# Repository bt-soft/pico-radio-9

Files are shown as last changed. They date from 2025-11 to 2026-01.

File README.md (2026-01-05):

# pico-radio-9

**A projekt még fejlesztés alatt áll!**

A projekt leírása: https://electrodiy.blog.hu/2026/01/01/pico_radio_fm_am_ssb_cw_rtty_sstv_wefax

## A kütyü
A kísérleti kütyü
<br/>

<em>A kísérleti kütyü (egy V7-es prototípus hangfrekis műveleti erősítővel kiegészítve)</em>
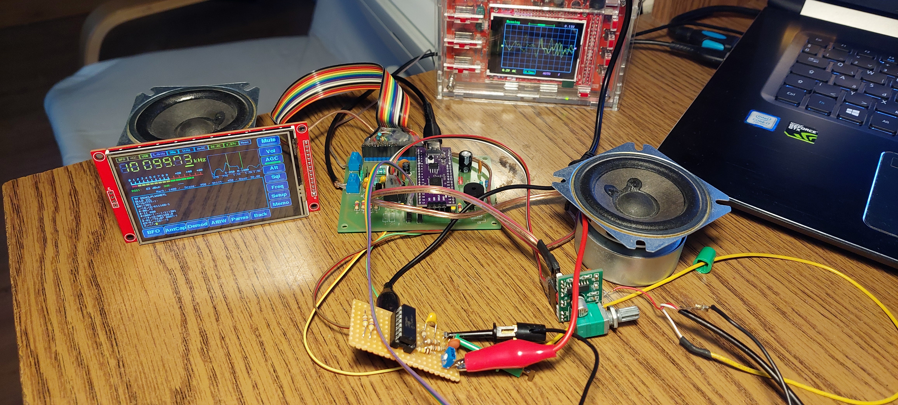
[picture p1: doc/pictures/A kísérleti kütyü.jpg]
A kísérleti kütyü

<br/>

### PCB 3D View

<table style="border:none; width:100%;">
  <tr>
    <td style="border:none; text-align:center; vertical-align:middle;">
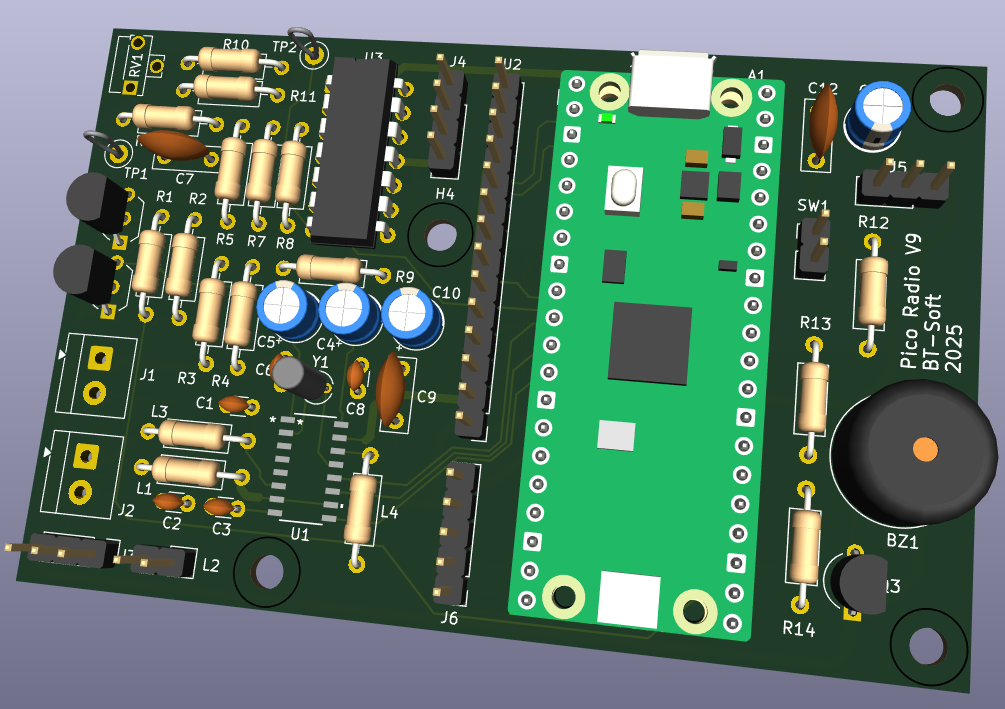
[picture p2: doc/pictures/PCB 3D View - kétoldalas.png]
PCB 3D View - kétoldalas
      
    </td>
    <td style="border:none; text-align:center; vertical-align:middle;">
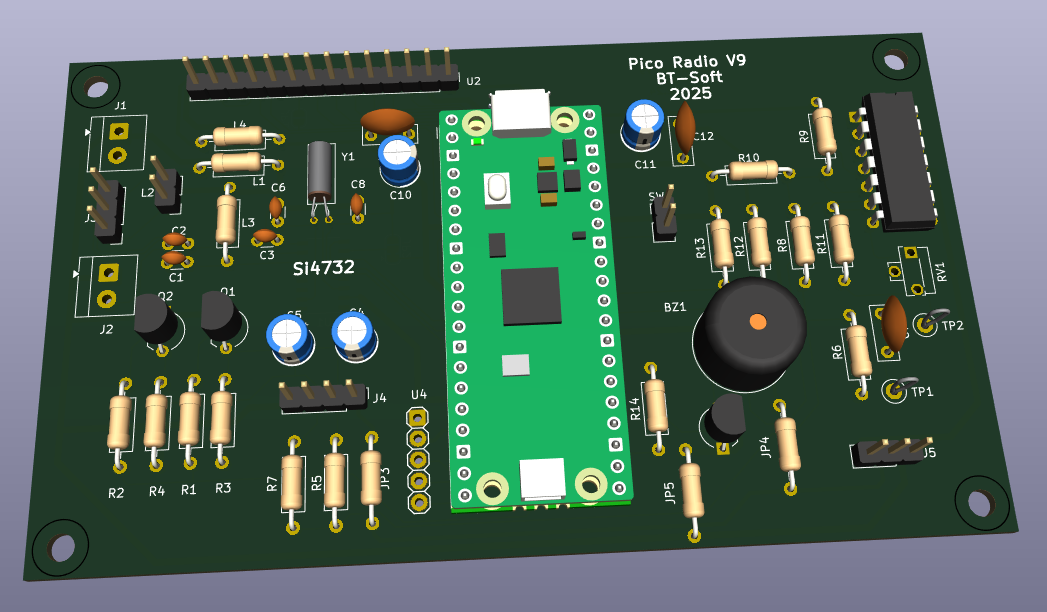
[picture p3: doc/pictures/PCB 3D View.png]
PCB 3D nézet - egyoldalas
      
    </td>
  </tr>
  <tr>
    <td style="border:none; text-align:center;">
      <em>Kétoldalas NYÁK terv</em>
    </td>
    <td style="border:none; text-align:center;">
      <em>Egyoldalas NYÁK terv</em>
    </td>
  </tr>
</table>

Egy Raspberry Pi Pico alapú rádióprojekt (Si4735 vezérléssel) — fejlett dekóderekkel (RTTY, CW, SSTV, WeFax), spektrum megjelenítéssel és interaktív érintőképernyős felülettel.

**Fő funkciók**
- Si4735 vezérlés (AM/FM/SDR jellegű demodok és RDS)
- Dekóderek: RTTY, CW, SSTV, WeFax, RTTY feldolgozó
- Valós idejű spektrum- és vízesés (low/high resolution bar, oscilloscope, envelope, waterfall, valamint CW/RTTY hangolássegéd waterfall és SNR burkoló) megjelenítők
- Hangfeldolgozó pipeline (AGC, FFT alapú vizualizáció manuális vagy automatikus erősítéssel)
- Rétegzett dialógus rendszer: többgombos dialógusok, értékmódosítók (rotary/touch)
- Konfigurációs tárolás EEPROM-ban (station/setting store)

## Architektúra
 - RP2040 / multicore: A Raspberry Pi Pico kétmagos RP2040 mikrovezérlője lehetővé teszi a feladatok elkülönítését (audio-feldolgozás a második magon, míg az első mag a UI/Si4735 vezérlést végzi). Ezt a projekt kihasználja a valós idejű audio dekódolás és UI műveletek párhuzamosítása érdekében.

## Technológiák

- Platform: Raspberry Pi Pico (RP2040)
- Fejlesztési környezet: PlatformIO 
- Framework: Arduino (RP2040 / Arduino core) 
- Nyelv: C++17 
- TFT vezérlés: `TFT_eSPI` — ILI9844 3.5" TFT grafikus megjelenítés és touch kezelése.
- Si4735 vezérlés: `PU2CLR SI4735` wrapper és a projekt saját `Si4735*` moduljai (I2C/SPI integráció és rádiófunkciók).
- Audio feldolgozás: FFT alapú spektrum- és vízesés (waterfall) megjelenítés, AGC és egyedi AudioProcessor pipeline.
- Dekóderek: RTTY, CW, SSTV, WeFax implementációk (saját `Decoder*` modulok).
- UI komponensek: egyedi komponenskeretrendszer (`UI*` osztályok) — dialógusok, többgombos menük, virtuális billentyűzet és grafikus komponensek.
- Időzítés és megszakítások: `RPI_PICO_TimerInterrupt` (PlatformIO lib) a pontos időzítéshez.
- FFT könyvtár: `arduinoFFT` a spektrum-számításokhoz.
- Helyi segédkönyvtárak: `lib/pico_sstv` az SSTV dekódoláshoz és segédfüggvényekhez.

## Felhasznált könyvtárak
- `Arduino-Pico`: https://github.com/earlephilhower/arduino-pico
- `TFT eSPI`: https://github.com/Bodmer/TFT_eSPI
- `RPI PICO TimerInterrupt`: https://github.com/khoih-prog/RPI_PICO_TimerInterrupt
- `PU2CLR SI4735`: https://github.com/pu2clr/SI4735
- `Arduino CMSIS-DSP`: https://www.arduinolibraries.info/libraries/arduino_cmsis-dsp
- `lib/pico_sstv`: https://github.com/dawsonjon/PicoSSTV

## Fájlok és modulok (összefoglaló)
- `src/` - forráskód (képernyők, dekóderek, UI komponensek, vezérlők)
  - `main.cpp`, `main-c1.cpp` - indító fájlok
  - `Screen*` - különböző képernyők (RTTY, CW, FM, AM, SSTV, WeFax, Setup, stb.)
  - `Decoder*` - dekóderek (RTTY, CW, SSTV, WeFax, stb.)
  - `UI*` - UI keretrensdszer komponensei (gombok, dialógusok, spektrum, textbox, stb.)
  - `Si4735*` - Si4735 kezelő és runtime logika
  - `AudioController.*`, `AudioProcessor-*` - audio pipeline és feldolgozás
- `include/` - header fájlok (összes osztály, UI, konfigurációs struktúrák)
  - `Config.h`, `ConfigData.h` - konfigurációs struktúrák és default értékek
  - `UIDialogBase.h`, `UIMultiButtonDialog.h`, `UIValueChangeDialog.h` - dialógusok és vezérlők
  - `UIHorizontalButtonBar.h` - alsó gombsor kezelése
- `lib/` - külső vagy saját könyvtárak (pl. `pico_sstv`, `CMSIS-DSP`)
- `doc/` - dokumentációs anyagok 
- `test/` - teszt erőforrások és példa adatállományok (pl. cw, rtty tesztek)

## Konfiguráció és mentés
- Konfigurációk a `Config` struktúrában találhatók (`include/Config.h`, `include/ConfigData.h`).
- Station / memory store beállítások EEPROM-ban tárolódnak (lásd `StationStore*` és `Eeprom*` fájlok).

## UI képernyők, dialógusok
- Rétegzett dialógus rendszer: a `UIScreen` tartalmaz egy dialógusstack-et, a `showDialog()` és `onDialogClosed()` mechanizmusokkal.
- Többgombos dialógusok: `UIMultiButtonDialog` + `UIValueChangeDialog` az értékek szerkesztéséhez.

## Szoftverarchitektúra
- Dekóderek: `src/Decoder*.cpp` — új dekóderek hozzáadása egyszerű az `IDecoder` interfész implementálásával.
- UI komponensek: `include/UI*`, `src/UI*` — gombok, dialógusok, új vizualizációk hozzáadása.
- Audio pipeline: `AudioController.cpp` és `AudioProcessor-*.cpp` fájlok tartalmazzák a feldolgozás logikáját.

## Hibakeresés / debug
- A forrásban `DEBUG(...)` makrók és logolási segédek találhatók. A debug build beállítása és a `__DEBUG` makró használata segíthet a problémakeresésben.

## Kapcsolási rajz / nyomtatott áramkör
- Kicad formátumban a `kicad` mappában (egy- és kétoldalas NYÁK tervvel).

---

## Harmadik féltől származó források
Az alábbi forrás nyújtottak inspirációkat a projekt fejlesztése és megvalósítása során.

 - **SI4735 + TFT példa (IU4ALH)**: https://github.com/IU4ALH/IU4ALH
  - Használat: Elsősorban a repó  `SI4735_2.8_TFT_SI5351_V.5.2b_Dark.zip` állományában található forrásokat használtam fel, amelyek inspirációt adtak a szolgáltatások, a képernyők felépítéséhez valamint az Si4735 beállítások kezeléséhez.

- **Rotary encoder / forgókapcsoló referencia**: https://www.mikrocontroller.net/articles/Drehgeber
  - Használat: A forgató encoder kezelésének elméleti háttere és debouncing/step logika inspirálására; segített a `RotaryEncoder` osztály és a forgóvezérlők finomhangolásában.

- **Pico SSTV implementáció**: https://github.com/dawsonjon/PicoSSTV
  - Használat: SSTV dekóder és mintafeldolgozó technikák inspirációjára használtam a projekt `DecoderSSTV` moduljának kialakításához.

- **fldigi**: https://github.com/w1hkj/fldigi
  - Használat: HF WeFax dekóder kiakalítása, technikai megoldások, szoftveres szűrők
---

## License
Projekt licenc: MIT

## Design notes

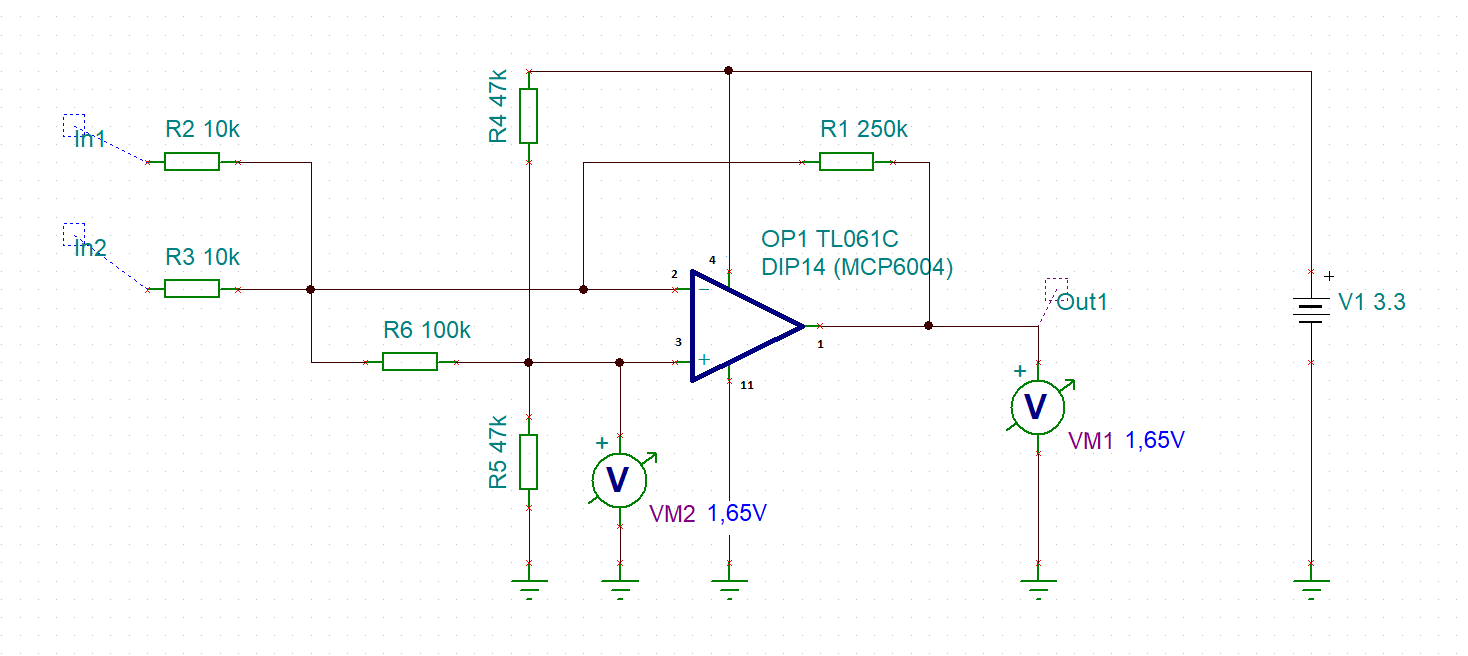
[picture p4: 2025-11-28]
doc/pictures/af preamp.png

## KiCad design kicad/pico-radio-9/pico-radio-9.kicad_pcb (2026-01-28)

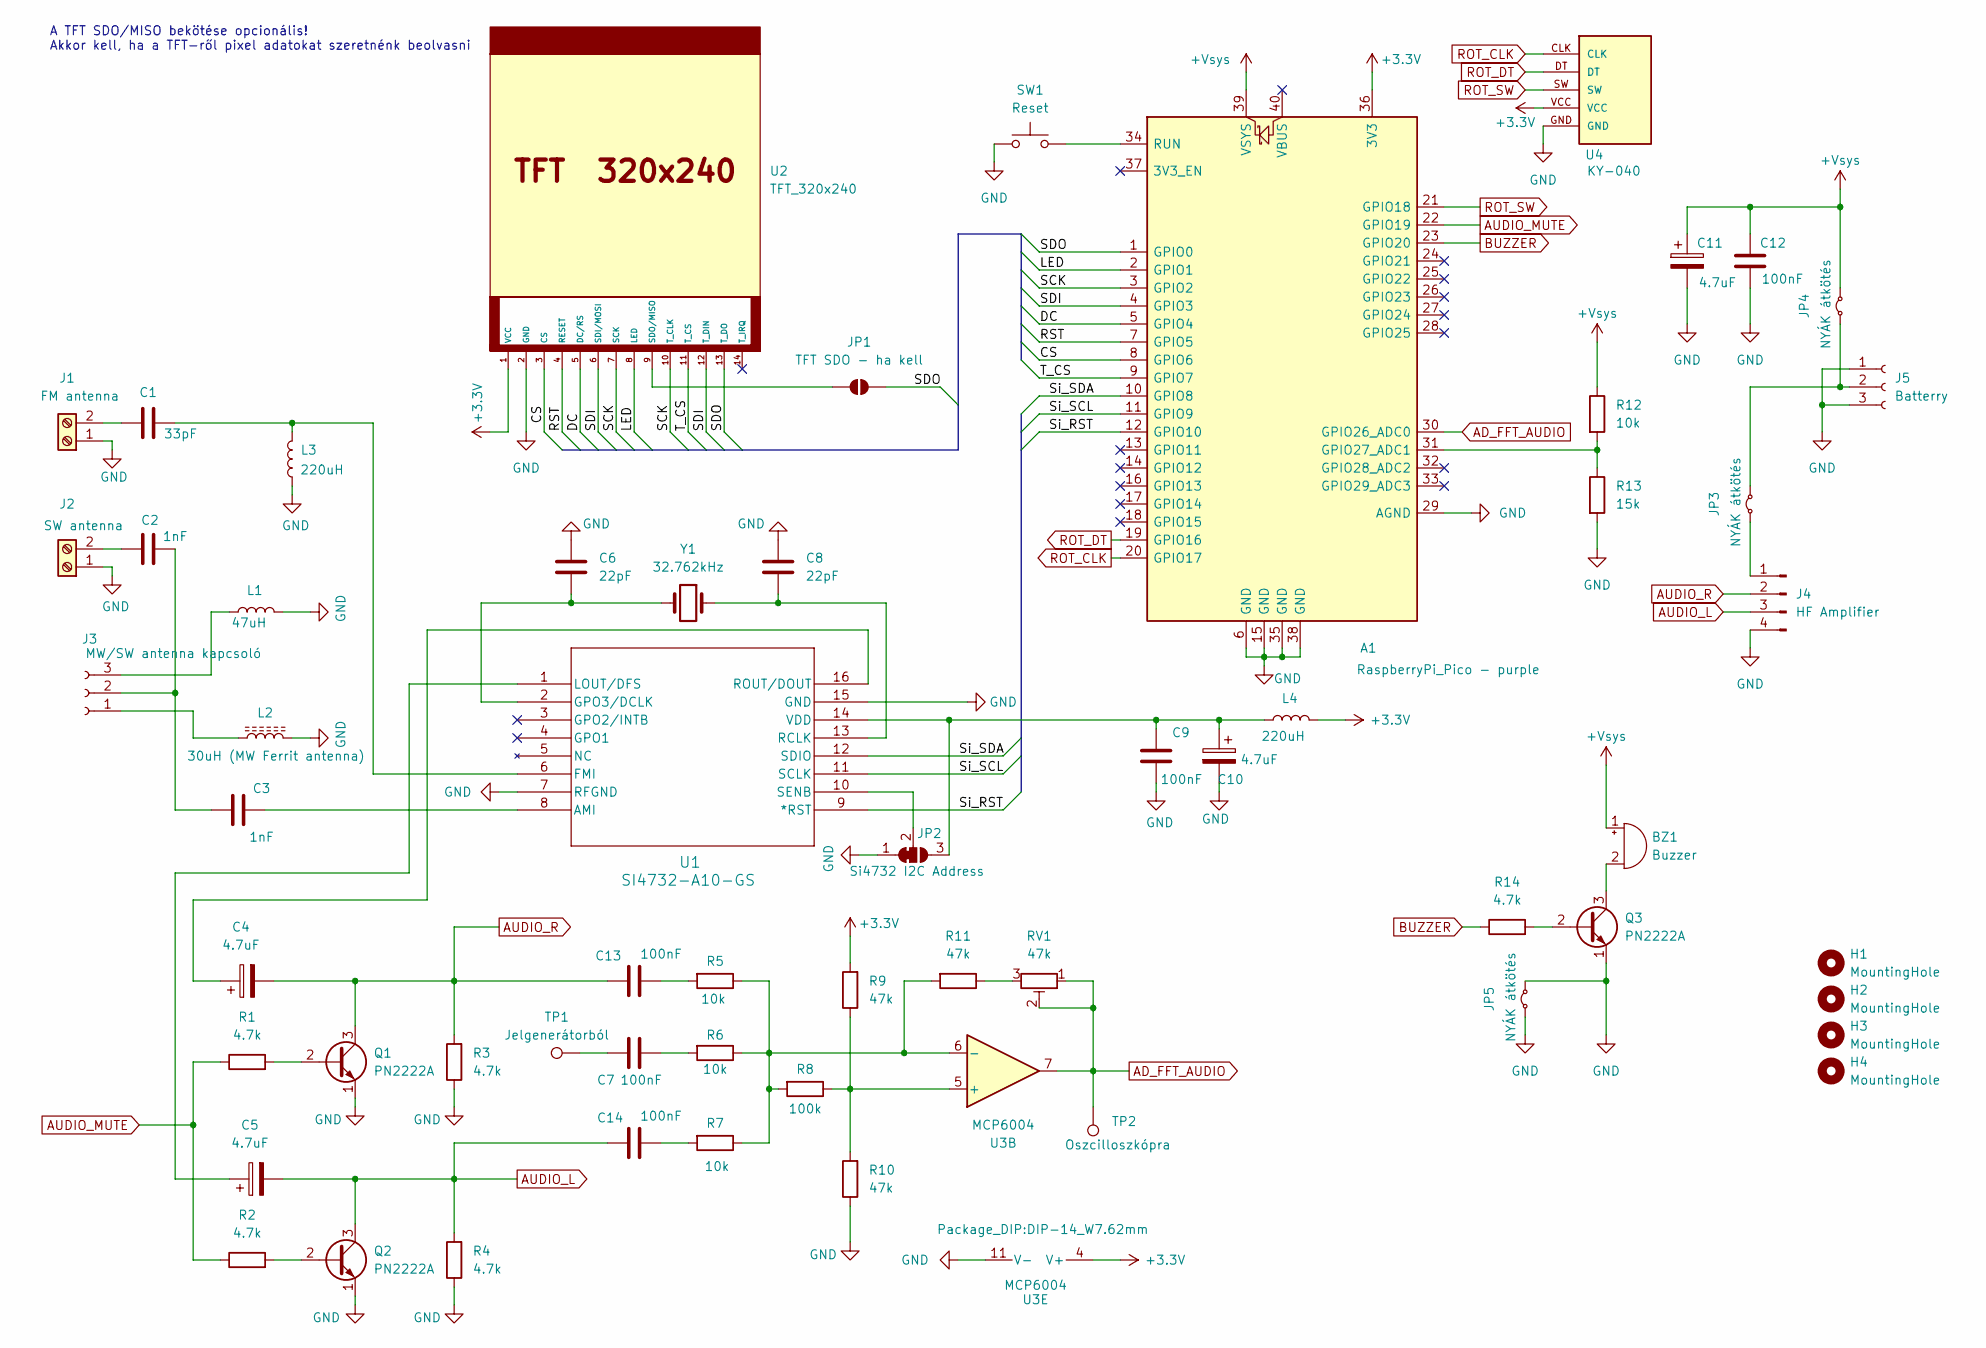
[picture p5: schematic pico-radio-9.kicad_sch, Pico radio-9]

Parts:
A1: RaspberryPi_Pico - purple; RaspberryPi_Pico_Common_THT-simple
BZ1: Buzzer; Buzzer_12x9.5RM7.6
C1: 33pF; C_Disc_D3.0mm_W1.6mm_P2.50mm
C2, C3: 1nF; C_Disc_D3.0mm_W1.6mm_P2.50mm
C4, C5, C10, C11: 4.7uF; CP_Radial_D5.0mm_P2.50mm
C6, C8: 22pF; C_Disc_D3.0mm_W1.6mm_P2.50mm
C7, C9, C12, C13, C14: 100nF; C_Disc_D7.0mm_W2.5mm_P5.00mm
H1, H2, H3, H4: MountingHole; MountingHole_3.2mm_M3
J1: FM antenna; TerminalBlock_4Ucon_1x02_P3.50mm_Horizontal
J2: SW antenna; TerminalBlock_4Ucon_1x02_P3.50mm_Horizontal
J3: MW/SW antenna kapcsoló; PinHeader_1x03_P2.54mm_Vertical
J4: HF Amplifier; PinHeader_1x04_P2.54mm_Vertical
J5: Batterry; PinHeader_1x03_P2.54mm_Vertical
JP1: TFT SDO - ha kell; SolderJumper-2_P1.3mm_Open_RoundedPad1.0x1.5mm
JP2: Si4732 I2C Address; SolderJumper-3_P1.3mm_Bridged12_RoundedPad1.0x1.5mm
JP3, JP4, JP5: NYÁK átkötés; R_Axial_DIN0207_L6.3mm_D2.5mm_P10.16mm_Horizontal
L1: 47uH; R_Axial_DIN0207_L6.3mm_D2.5mm_P10.16mm_Horizontal
L2: 30uH (MW Ferrit antenna); PinHeader_1x02_P2.54mm_Vertical
L3, L4: 220uH; R_Axial_DIN0207_L6.3mm_D2.5mm_P10.16mm_Horizontal
Q1, Q2, Q3: PN2222A; TO-92_Inline_Wide
R1, R2, R3, R4, R14: 4.7k; R_Axial_DIN0207_L6.3mm_D2.5mm_P10.16mm_Horizontal
R5, R6, R7, R12: 10k; R_Axial_DIN0207_L6.3mm_D2.5mm_P10.16mm_Horizontal
R8: 100k; R_Axial_DIN0207_L6.3mm_D2.5mm_P10.16mm_Horizontal
R9, R10, R11: 47k; R_Axial_DIN0207_L6.3mm_D2.5mm_P10.16mm_Horizontal
R13: 15k; R_Axial_DIN0207_L6.3mm_D2.5mm_P10.16mm_Horizontal
RV1: 47k; Potentiometer_Runtron_RM-063_Horizontal
SW1: Reset; PinHeader_1x02_P2.54mm_Vertical
TP1: Jelgenerátorból; TestPoint_Loop_D2.50mm_Drill1.0mm
TP2: Oszcilloszkópra; TestPoint_Loop_D2.50mm_Drill1.0mm
U1: SI4732-A10-GS; SOIC_A10-GS_SIL
U2: TFT_320x240; PinHeader_1x14_P2.54mm_Vertical
U3: MCP6004; DIP-14_W7.62mm
U4: KY-040; KY-040-PORT
Y1: 32.762kHz; Crystal_C38-LF_D3.0mm_L8.0mm_Horizontal

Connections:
+3.3V: A1.36 (3V3), L4.2, R9.2, U2.1 (VCC), U3.4 (V+), U4.VCC
+Vsys: A1.39 (VSYS), BZ1.1 (+), C11.1, C12.1, JP4.2 (B), R12.1
/CS: A1.8 (GPIO6), U2.3 (CS)
/DC: A1.5 (GPIO4), U2.5 (DC/RS)
/LED: A1.2 (GPIO1), U2.8 (LED)
/RST: A1.7 (GPIO5), U2.4 (RESET)
/SCK: A1.3 (GPIO2), U2.7 (SCK), U2.10 (T_CLK)
/SDI: A1.4 (GPIO3), U2.6 (SDI/MOSI), U2.12 (T_DIN)
/SDO: A1.1 (GPIO0), JP1.2 (B), U2.13 (T_DO)
/Si_RST: A1.12 (GPIO10), U1.9 (*RST)
/Si_SCL: A1.11 (GPIO9), U1.11 (SCLK)
/Si_SDA: A1.10 (GPIO8), U1.12 (SDIO)
/T_CS: A1.9 (GPIO7), U2.11 (T_CS)
AD_FFT_AUDIO: A1.30 (GPIO26_ADC0), RV1.1, RV1.2, TP2.1, U3.7
AUDIO_L: C5.2, C14.2, J4.3, Q2.3 (C), R4.2
AUDIO_MUTE: A1.22 (GPIO19), R1.1, R2.1
AUDIO_R: C4.2, C13.2, J4.2, Q1.3 (C), R3.2
BUZZER: A1.23 (GPIO20), R14.1
GND: A1.6 (GND), A1.15 (GND), A1.29 (AGND), A1.35 (GND), A1.38 (GND), C6.2, C8.1, C9.1, C10.2, C11.2, C12.2, J1.1, J2.1, J4.4, J5.1, J5.3, JP2.1 (A), JP5.1 (A), JP5.2 (B), L1.2, L2.2, L3.1, Q1.1 (E), Q2.1 (E), Q3.1 (E), R3.1, R4.1, R10.1, R13.2, SW1.1, U1.7 (RFGND), U1.15 (GND), U2.2 (GND), U3.11 (V-), U4.GND
unnamed: A1.31 (GPIO27_ADC1), R12.2, R13.1
unnamed: A1.34 (RUN), SW1.2
unnamed: BZ1.2 (-), Q3.3 (C)
unnamed: C7.1, R6.2
unnamed: C7.2, TP1.1
unnamed: C13.1, R5.2
unnamed: C14.1, R7.2
unnamed: C1.2, J1.2
unnamed: C2.1, J2.2
unnamed: J3.1, L2.1
unnamed: C2.2, C3.2, J3.2
unnamed: J3.3, L1.1
unnamed: J4.1, JP3.1 (A)
unnamed: J5.2, JP3.2 (B), JP4.1 (A)
unnamed: JP1.1 (A), U2.9 (SDO/MISO)
unnamed: C9.2, C10.1, JP2.3 (B), L4.1, U1.14 (VDD)
unnamed: JP2.2 (C), U1.10 (SENB)
unnamed: Q1.2 (B), R1.2
unnamed: Q2.2 (B), R2.2
unnamed: Q3.2 (B), R14.2
unnamed: R11.1, RV1.3
unnamed: C3.1, U1.8 (AMI)
unnamed: C1.1, L3.2, U1.6 (FMI)
unnamed: C6.1, U1.2 (GPO3/DCLK), Y1.2
unnamed: C5.1, U1.1 (LOUT/DFS)
unnamed: C8.2, U1.13 (RCLK), Y1.1
unnamed: C4.1, U1.16 (ROUT/DOUT)
unnamed: R8.1, R9.1, R10.2, U3.5 (+)
unnamed: R5.1, R6.1, R7.1, R8.2, R11.2, U3.6 (-)
ROT_CLK: A1.20 (GPIO17), U4.CLK
ROT_DT: A1.19 (GPIO16), U4.DT
ROT_SW: A1.21 (GPIO18), U4.SW

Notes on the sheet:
A TFT SDO/MISO bekötése opcionális! Akkor kell, ha a TFT-ről pixel adatokat szeretnénk beolvasni

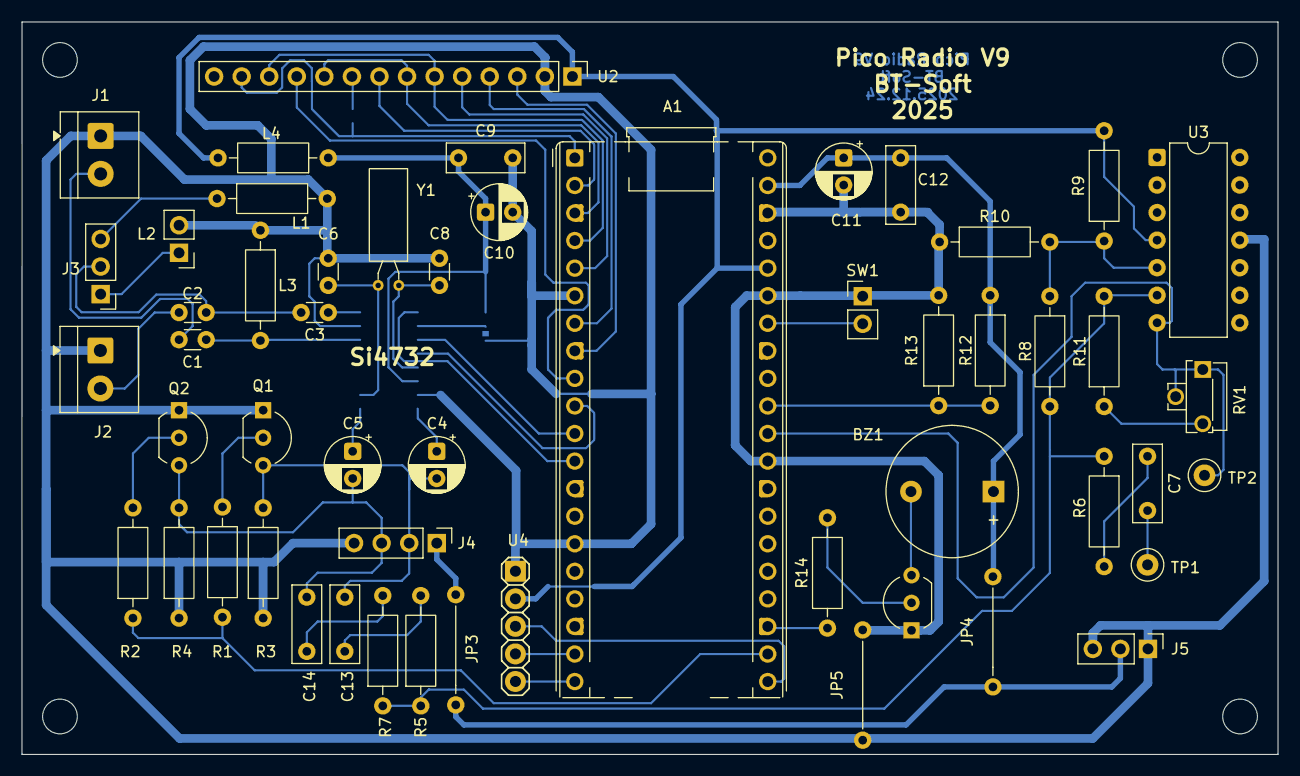
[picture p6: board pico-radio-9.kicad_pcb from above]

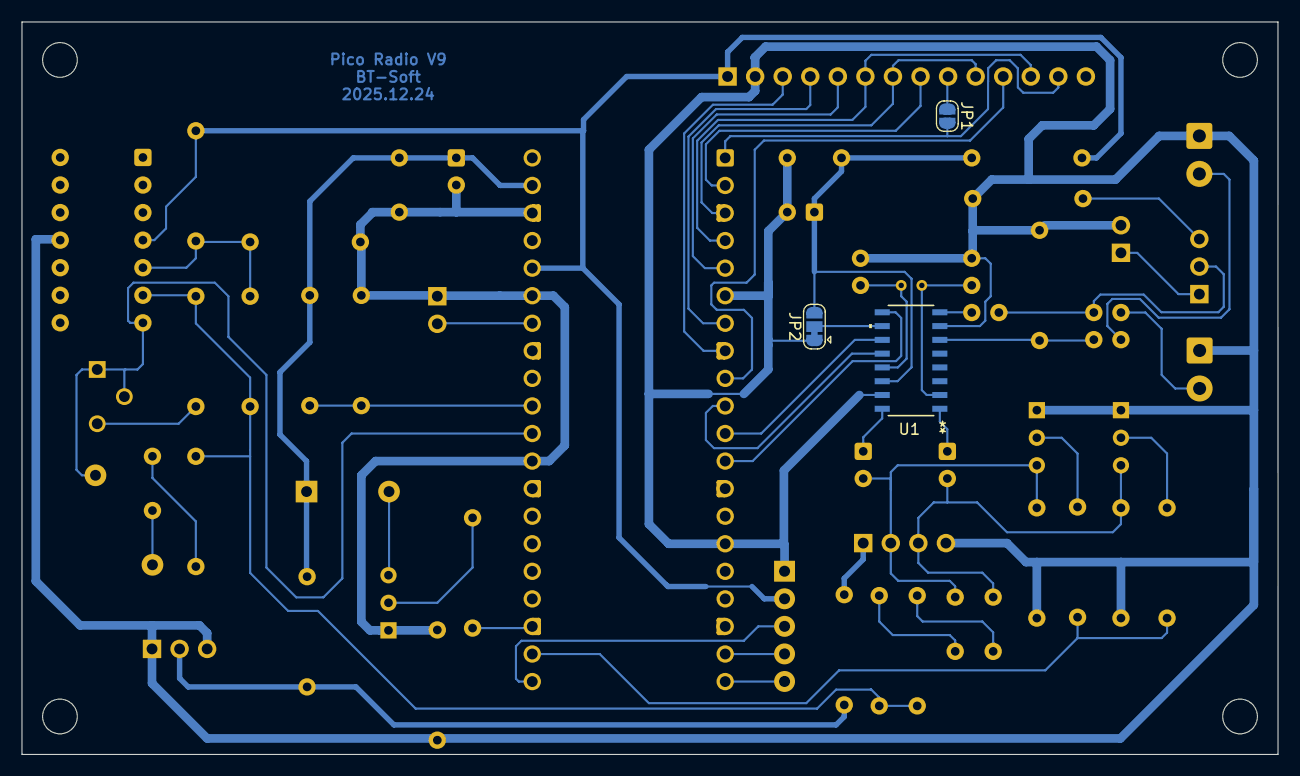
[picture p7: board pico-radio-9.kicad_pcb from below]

Board: 2 copper layers, 115.8 x 67.5 mm, 60 parts (3 on the bottom side), 51 nets.

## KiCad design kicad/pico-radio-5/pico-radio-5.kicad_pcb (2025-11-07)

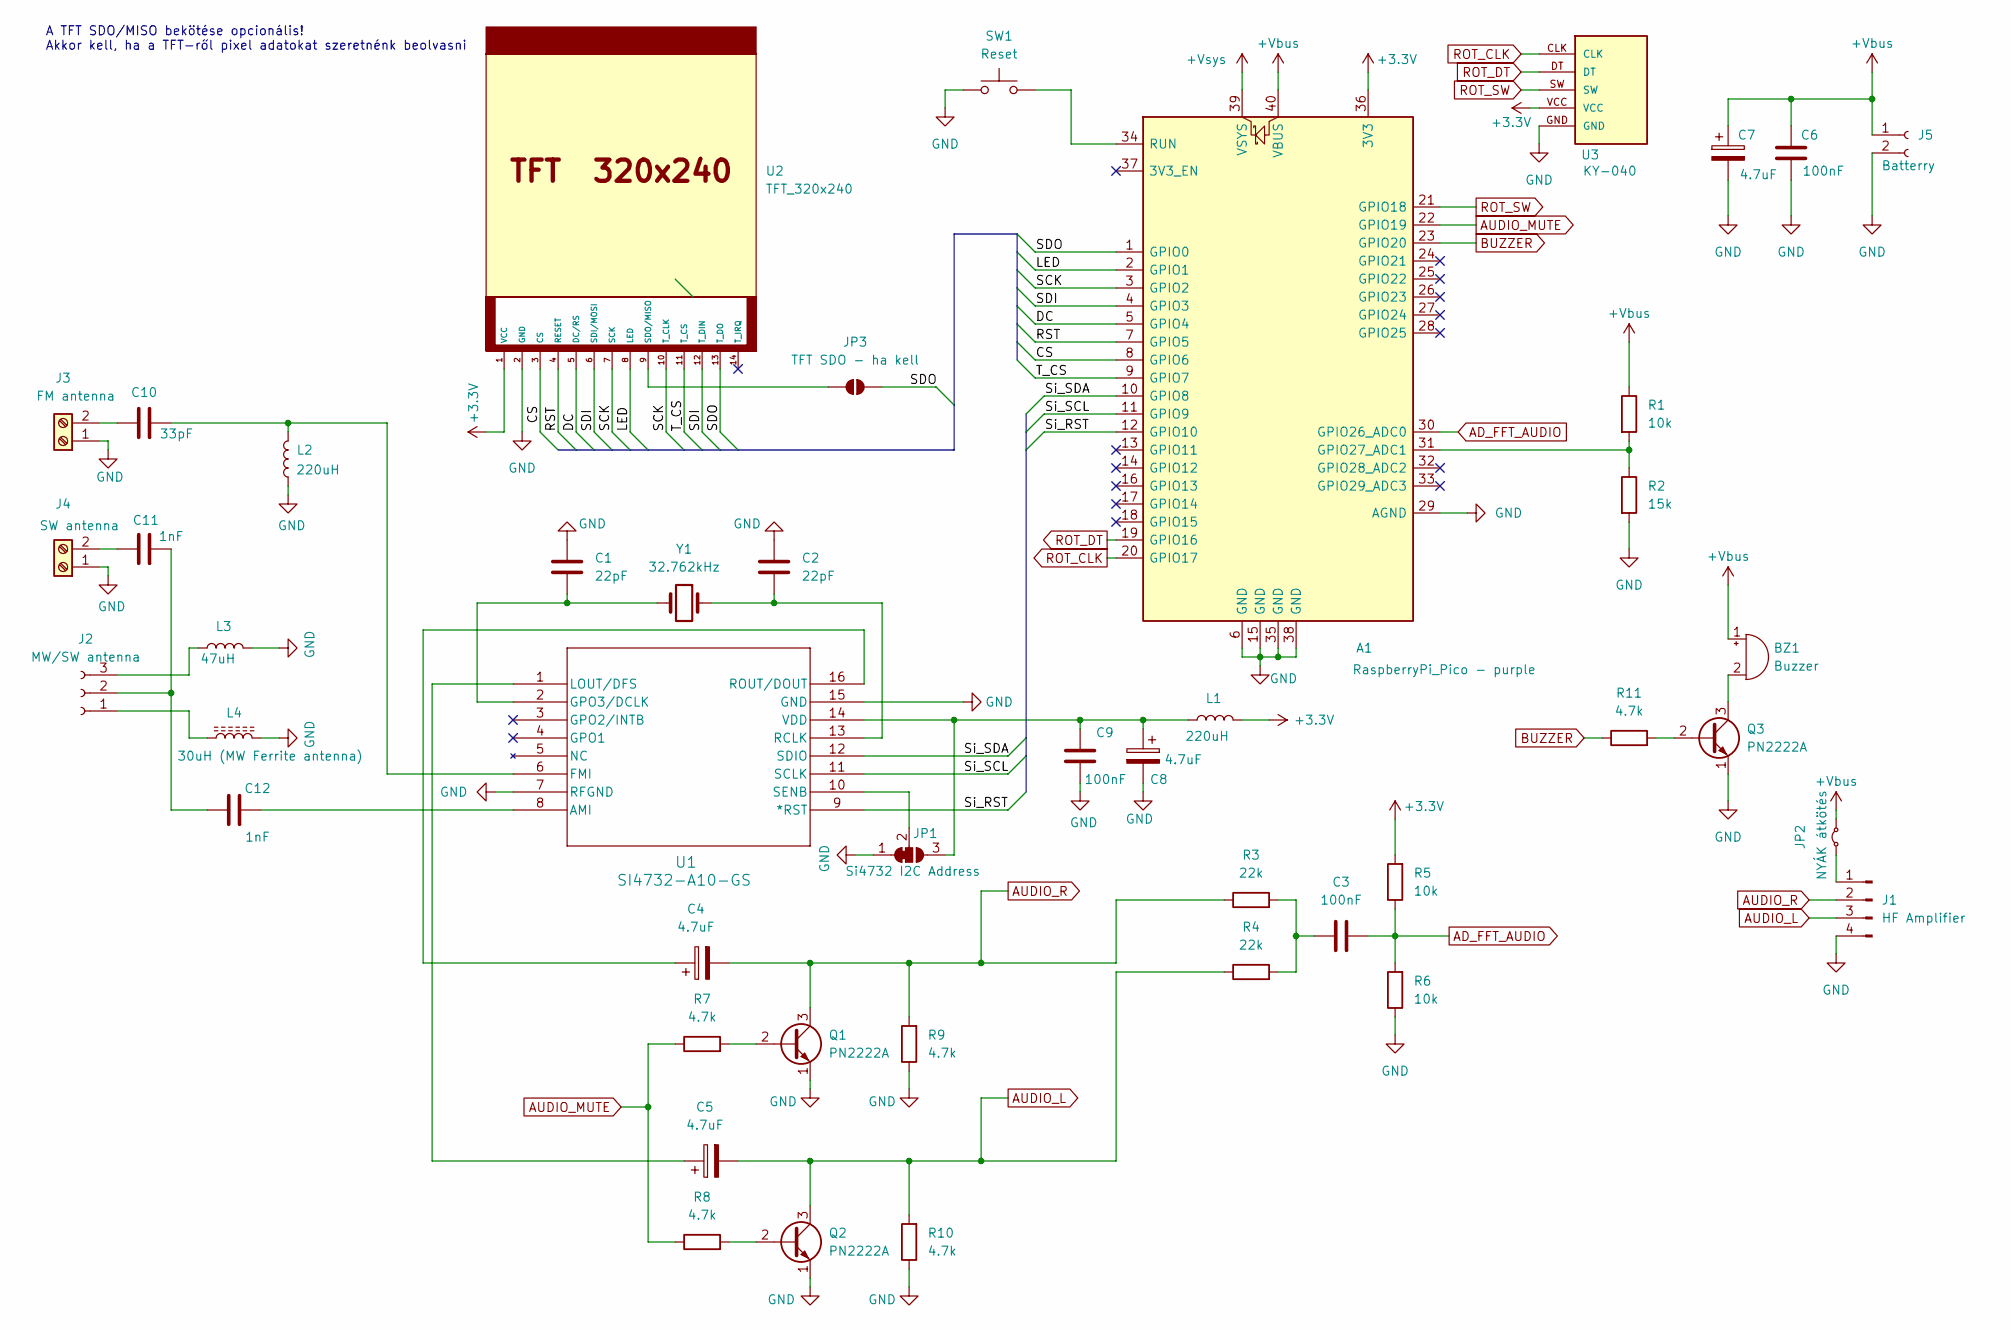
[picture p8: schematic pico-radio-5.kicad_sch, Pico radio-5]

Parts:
A1: RaspberryPi_Pico - purple; RaspberryPi_Pico_Common_THT-simple
BZ1: Buzzer; Buzzer_12x9.5RM7.6
C1, C2: 22pF; C_Disc_D3.0mm_W1.6mm_P2.50mm
C3, C6, C9: 100nF; C_Disc_D7.0mm_W2.5mm_P5.00mm
C4, C5, C7, C8: 4.7uF; CP_Radial_D5.0mm_P2.50mm
C10: 33pF; C_Disc_D3.0mm_W1.6mm_P2.50mm
C11, C12: 1nF; C_Disc_D3.0mm_W1.6mm_P2.50mm
J1: HF Amplifier; PinHeader_1x04_P2.54mm_Vertical
J2: MW/SW antenna; PinHeader_1x03_P2.54mm_Vertical
J3: FM antenna; TerminalBlock_4Ucon_1x02_P3.50mm_Horizontal
J4: SW antenna; TerminalBlock_4Ucon_1x02_P3.50mm_Horizontal
J5: Batterry; PinHeader_1x02_P2.54mm_Vertical
JP1: Si4732 I2C Address; SolderJumper-3_P1.3mm_Bridged12_RoundedPad1.0x1.5mm
JP2: NYÁK átkötés; R_Axial_DIN0207_L6.3mm_D2.5mm_P10.16mm_Horizontal
JP3: TFT SDO - ha kell; SolderJumper-2_P1.3mm_Open_RoundedPad1.0x1.5mm
L1, L2: 220uH; R_Axial_DIN0207_L6.3mm_D2.5mm_P10.16mm_Horizontal
L3: 47uH; R_Axial_DIN0207_L6.3mm_D2.5mm_P10.16mm_Horizontal
L4: 30uH (MW Ferrite antenna); PinHeader_1x02_P2.54mm_Vertical
Q1, Q2, Q3: PN2222A; TO-92_Inline
R1, R5, R6: 10k; R_Axial_DIN0207_L6.3mm_D2.5mm_P10.16mm_Horizontal
R2: 15k; R_Axial_DIN0207_L6.3mm_D2.5mm_P10.16mm_Horizontal
R3, R4: 22k; R_Axial_DIN0207_L6.3mm_D2.5mm_P10.16mm_Horizontal
R7, R8, R9, R10, R11: 4.7k; R_Axial_DIN0207_L6.3mm_D2.5mm_P10.16mm_Horizontal
SW1: Reset; PinHeader_1x02_P2.54mm_Vertical
U1: SI4732-A10-GS; SOIC_A10-GS_SIL
U2: TFT_320x240; PinHeader_1x14_P2.54mm_Vertical
U3: KY-040; KY-040-PORT
Y1: 32.762kHz; Crystal_C38-LF_D3.0mm_L8.0mm_Horizontal

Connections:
+3.3V: A1.36 (3V3), L1.2, R5.2, U2.1 (VCC), U3.VCC
+Vbus: A1.40 (VBUS), BZ1.1 (+), C6.1, C7.1, J5.1, JP2.2 (B), R1.1
+Vsys: A1.39 (VSYS)
/CS: A1.8 (GPIO6), U2.3 (CS)
/DC: A1.5 (GPIO4), U2.5 (DC/RS)
/LED: A1.2 (GPIO1), U2.8 (LED)
/RST: A1.7 (GPIO5), U2.4 (RESET)
/SCK: A1.3 (GPIO2), U2.7 (SCK), U2.10 (T_CLK)
/SDI: A1.4 (GPIO3), U2.6 (SDI/MOSI), U2.12 (T_DIN)
/SDO: A1.1 (GPIO0), JP3.2 (B), U2.13 (T_DO)
/Si_RST: A1.12 (GPIO10), U1.9 (*RST)
/Si_SCL: A1.11 (GPIO9), U1.11 (SCLK)
/Si_SDA: A1.10 (GPIO8), U1.12 (SDIO)
/T_CS: A1.9 (GPIO7), U2.11 (T_CS)
AD_FFT_AUDIO: A1.30 (GPIO26_ADC0), C3.2, R5.1, R6.2
AUDIO_L: C5.2, J1.3, Q2.3 (C), R4.1, R10.2
AUDIO_MUTE: A1.22 (GPIO19), R7.1, R8.1
AUDIO_R: C4.2, J1.2, Q1.3 (C), R3.1, R9.2
BUZZER: A1.23 (GPIO20), R11.1
GND: A1.6 (GND), A1.15 (GND), A1.29 (AGND), A1.35 (GND), A1.38 (GND), C1.2, C2.1, C6.2, C7.2, C8.2, C9.1, J1.4, J3.1, J4.1, J5.2, JP1.1 (A), L2.1, L3.2, L4.2, Q1.1 (E), Q2.1 (E), Q3.1 (E), R2.2, R6.1, R9.1, R10.1, SW1.1, U1.7 (RFGND), U1.15 (GND), U2.2 (GND), U3.GND
unnamed: A1.31 (GPIO27_ADC1), R1.2, R2.1
unnamed: A1.34 (RUN), SW1.2
unnamed: BZ1.2 (-), Q3.3 (C)
unnamed: C3.1, R3.2, R4.2
unnamed: J1.1, JP2.1 (A)
unnamed: J2.1, L4.1
unnamed: C11.2, C12.2, J2.2
unnamed: J2.3, L3.1
unnamed: C10.2, J3.2
unnamed: C11.1, J4.2
unnamed: C8.1, C9.2, JP1.3 (B), L1.1, U1.14 (VDD)
unnamed: JP1.2 (C), U1.10 (SENB)
unnamed: JP3.1 (A), U2.9 (SDO/MISO)
unnamed: Q1.2 (B), R7.2
unnamed: Q2.2 (B), R8.2
unnamed: Q3.2 (B), R11.2
unnamed: C12.1, U1.8 (AMI)
unnamed: C10.1, L2.2, U1.6 (FMI)
unnamed: C1.1, U1.2 (GPO3/DCLK), Y1.2
unnamed: C5.1, U1.1 (LOUT/DFS)
unnamed: C2.2, U1.13 (RCLK), Y1.1
unnamed: C4.1, U1.16 (ROUT/DOUT)
ROT_CLK: A1.20 (GPIO17), U3.CLK
ROT_DT: A1.19 (GPIO16), U3.DT
ROT_SW: A1.21 (GPIO18), U3.SW

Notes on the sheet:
A TFT SDO/MISO bekötése opcionális! Akkor kell, ha a TFT-ről pixel adatokat szeretnénk beolvasni

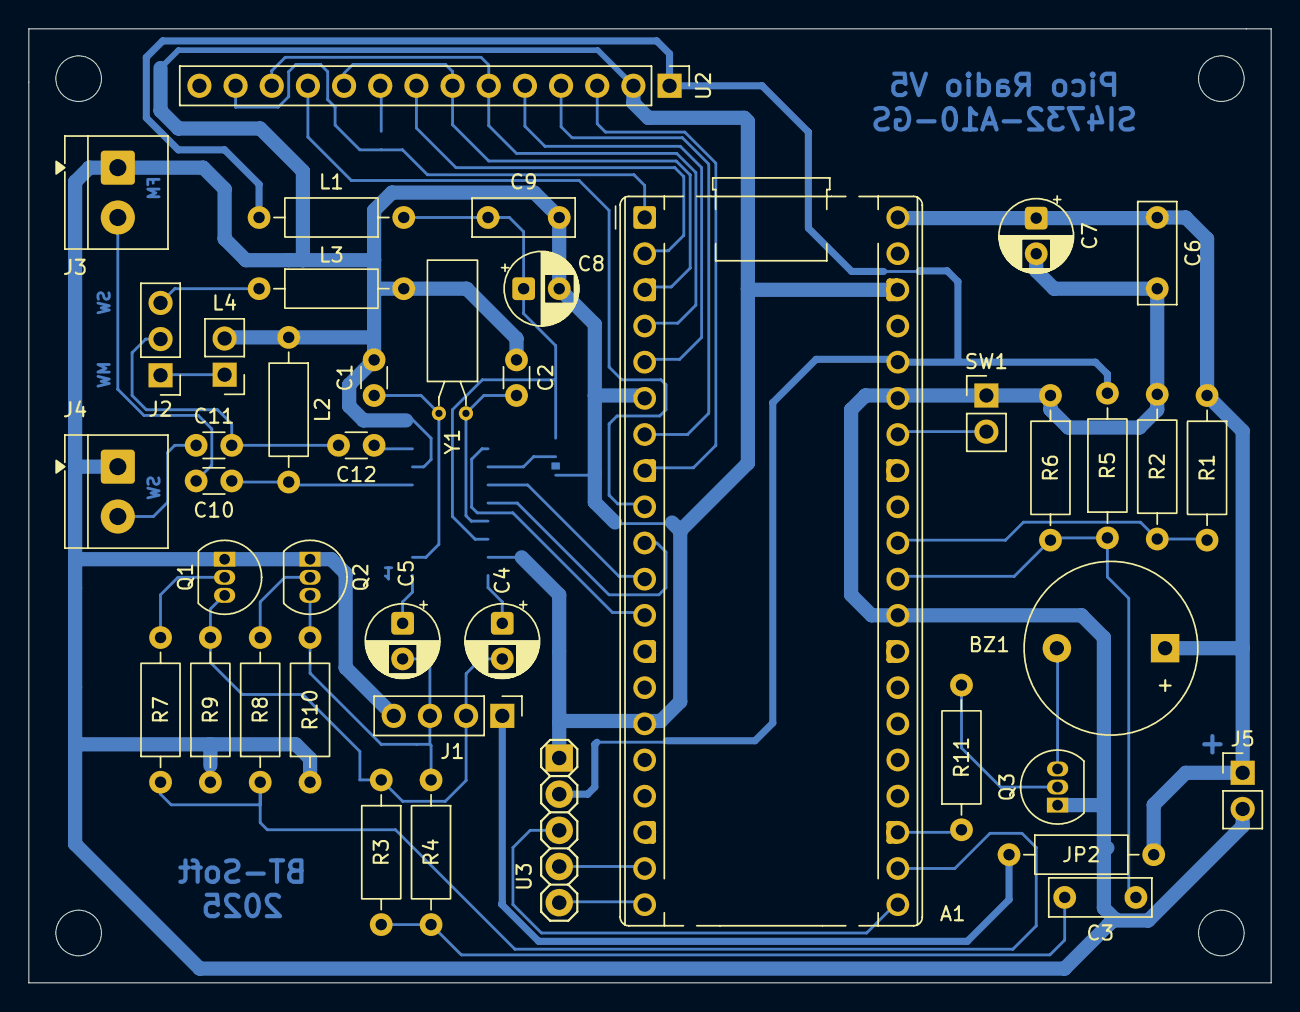
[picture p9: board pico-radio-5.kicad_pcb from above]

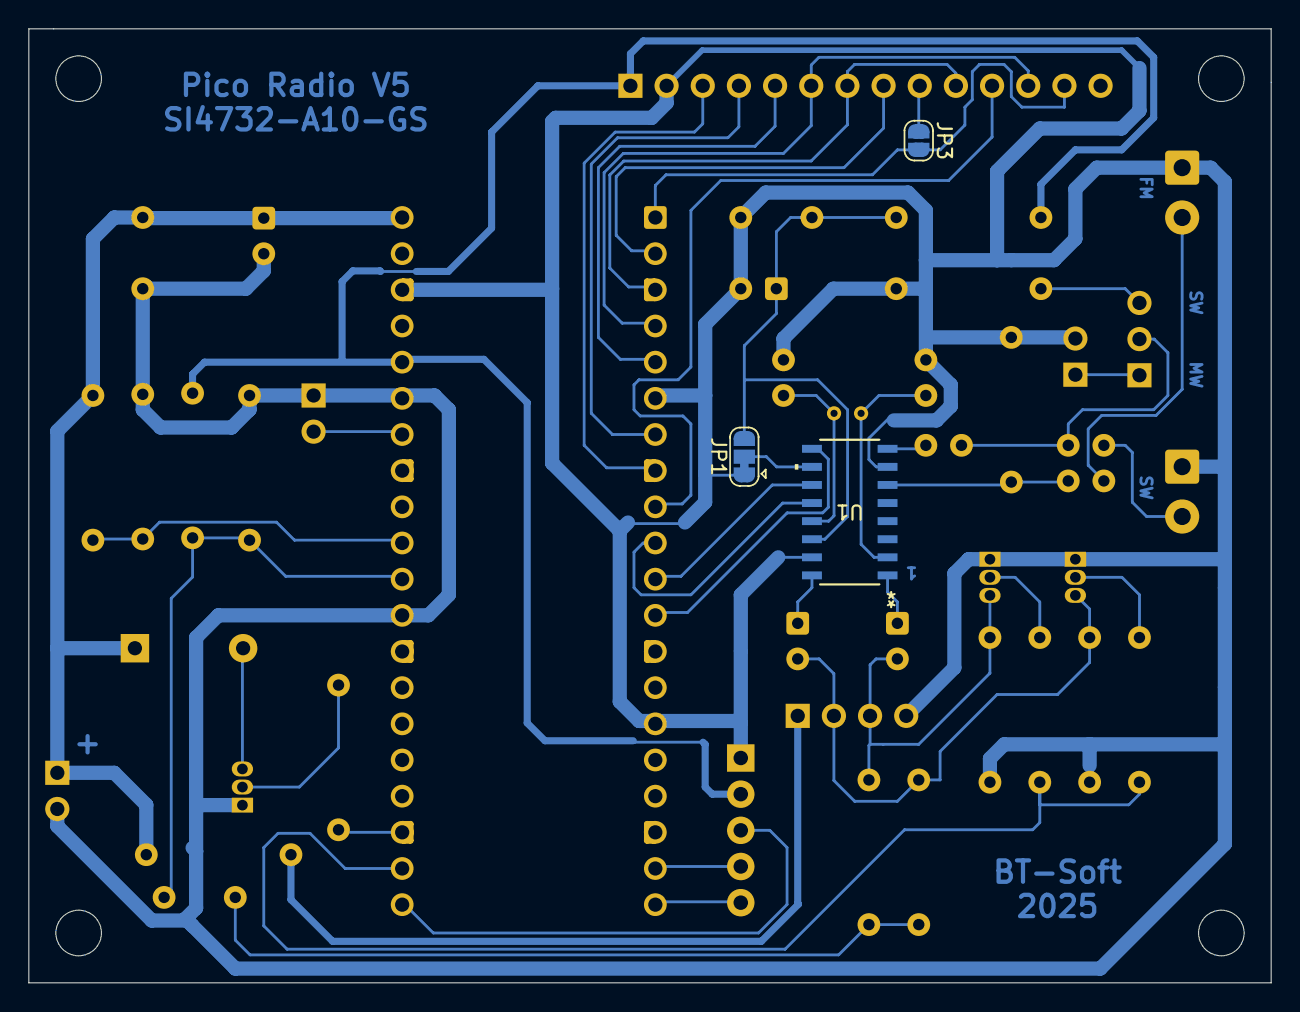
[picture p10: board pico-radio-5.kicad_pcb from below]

Board: 2 copper layers, 87.2 x 67.0 mm, 45 parts (3 on the bottom side), 44 nets.

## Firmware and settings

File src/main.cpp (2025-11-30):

/*
 * Project: [pico-radio-9] Raspberry Pi Pico Si4735 Radio                                                              *
 * File: main.cpp                                                                                                      *
 * Created Date: 2025.11.08.                                                                                           *
 *                                                                                                                     *
 * Author: BT-Soft                                                                                                     *
 * GitHub: https://github.com/bt-soft                                                                                  *
 * Blog: https://electrodiy.blog.hu/                                                                                   *
 * -----                                                                                                               *
 * Copyright (c) 2025 BT-Soft                                                                                          *
 * License: MIT License                                                                                                *
 * 	Bárki szabadon használhatja, módosíthatja, terjeszthet, beépítheti más                                             *
 * 	projektbe (akár zártkódúba is), akár pénzt is kereshet vele                                                        *
 * 	Egyetlen feltétel:                                                                                                 *
 * 		a licencet és a szerző nevét meg kell tartani a forrásban!                                                     *
 * -----                                                                                                               *
 * Last Modified: 2025.11.30, Sunday  05:04:01                                                                         *
 * Modified By: BT-Soft                                                                                                *
 * -----                                                                                                               *
 * HISTORY:                                                                                                            *
 * Date      	By	Comments                                                                                           *
 * ----------	---	-------------------------------------------------------------------------------------------------  *
 */

#include <Arduino.h>

#include "PicoMemoryInfo.h"
#include "PicoSensorUtils.h"
#include "SplashScreen.h"

#ifdef __DEBUG
// Soros portra várakozás az induláskor debug módban
// #define DEBUG_WAIT_FOR_SERIAL
// Memória monitor bekapcsolása az esteleges memory leak nyomon követésére
// #define SHOW_MEMORY_INFO
#endif

//------------------ TFT
#include <TFT_eSPI.h>
TFT_eSPI tft;
uint16_t SCREEN_W;
uint16_t SCREEN_H;

//------------------- Rotary Encoder
#include <RPi_Pico_TimerInterrupt.h>
RPI_PICO_Timer rotaryTimer(0); // 0-ás timer használata
#include "RotaryEncoder.h"
RotaryEncoder rotaryEncoder = RotaryEncoder(PIN_ENCODER_CLK, PIN_ENCODER_DT, PIN_ENCODER_SW, ROTARY_ENCODER_STEPS_PER_NOTCH);
#define ROTARY_ENCODER_SERVICE_INTERVAL_IN_MSEC 1 // 1msec

//-------------------- Config
#include "BandStore.h"
#include "Config.h"
#include "EepromLayout.h"
#include "StationStore.h"
#include "StoreEepromBase.h"
extern Config config;
extern FmStationStore fmStationStore;
extern AmStationStore amStationStore;
extern BandStore bandStore;

//------------------ SI4735
#include "Band.h" // Band típusok konstansaihoz
#include "Si4735Manager.h"
Si4735Manager *pSi4735Manager = nullptr; // Si4735Manager: NEM lehet (hardware inicializálás miatt) statikus, mert HW inicializálások is vannak benne

//-------------------- Screens
// Globális képernyőkezelő pointer - inicializálás a setup()-ban történik
#include "ScreenManager.h"
ScreenManager *screenManager = nullptr;
IScreenManager **iScreenManager = (IScreenManager **)&screenManager; // A UIComponent használja

//-------------------- AudioController
#include "AudioController.h"
AudioController audioController;

/**
 * @brief  Hardware timer interrupt service routine a rotaryhoz
 */
bool rotaryTimerHardwareInterruptHandler(struct repeating_timer *t) {
    rotaryEncoder.service();
    return true;
}

/**
 * @brief Rotary encoder események feldolgozása és továbbítása a ScreenManager-nek
 */
void processRotaryEncoderEvent() {

    // RotaryEncoder állapotának lekérdezése
    RotaryEncoder::EncoderState encoderState = rotaryEncoder.read();

    // Ha nem tekergetik vagy nincs gombnyomás, akkor nem csinálunk semmit
    if (encoderState.direction == RotaryEncoder::Direction::None && encoderState.buttonState == RotaryEncoder::ButtonState::Open) {
        return;
    }

    // Rotary tekerés irány lekérdezése
    RotaryEvent::Direction direction = RotaryEvent::Direction::None;
    if (encoderState.direction == RotaryEncoder::Direction::Up) {
        direction = RotaryEvent::Direction::Up;
    } else if (encoderState.direction == RotaryEncoder::Direction::Down) {
        direction = RotaryEvent::Direction::Down;
    }

    // Rotary gomb állapot lekérdezése
    RotaryEvent::ButtonState buttonState = RotaryEvent::ButtonState::NotPressed;
    if (encoderState.buttonState == RotaryEncoder::ButtonState::Clicked) {
        buttonState = RotaryEvent::ButtonState::Clicked;
    } else if (encoderState.buttonState == RotaryEncoder::ButtonState::DoubleClicked) {
        buttonState = RotaryEvent::ButtonState::DoubleClicked;
    }

    // Esemény továbbítása a ScreenManager-nek
    RotaryEvent rotaryEvent(direction, buttonState, encoderState.value);
    screenManager->handleRotary(rotaryEvent);
}

/**
 * @brief Touch események feldolgozása és továbbítása a ScreenManager-nek
 */
void processTouchEvent() {

    static uint16_t lastTouchX = 0;
    static uint16_t lastTouchY = 0;

    uint16_t touchX, touchY;
    bool touchedRaw = tft.getTouch(&touchX, &touchY);
    bool validCoordinates = true;
    if (touchedRaw) {
        if (touchX > SCREEN_W || touchY > SCREEN_H) {
            validCoordinates = false;
        }
    }
    bool touched = touchedRaw && validCoordinates;

    static bool lastTouchState = false;
    // Touch press event (immediate response)
    if (touched && !lastTouchState) {
        TouchEvent touchEvent(touchX, touchY, true);
        screenManager->handleTouch(touchEvent);
        lastTouchX = touchX;
        lastTouchY = touchY;
    } else if (!touched && lastTouchState) { // Touch release event (immediate response)
        TouchEvent touchEvent(lastTouchX, lastTouchY, false);
        screenManager->handleTouch(touchEvent);
    }

    lastTouchState = touched;
}

/**
 * @brief Core0 main belépő függvénye
 */
void setup() {
#ifdef __DEBUG
    Serial.begin(115200);
#endif

    // PICO AD inicializálása
    PicoSensorUtils::init();

    // Beeper
    pinMode(PIN_BEEPER, OUTPUT);
    digitalWrite(PIN_BEEPER, LOW);

    // TFT LED háttérvilágítás kimenet
    pinMode(PIN_TFT_BACKGROUND_LED, OUTPUT);
    Utils::setTftBacklight(TFT_BACKGROUND_LED_MAX_BRIGHTNESS); // TFT inicializálása DC módban
    tft.init();
    tft.setRotation(1);
    tft.fillScreen(TFT_BLACK); // Fekete háttér a splash screen-hez

    // UI komponensek számára képernyő méretek inicializálása
    SCREEN_W = tft.width();
    SCREEN_H = tft.height();

#if defined(__DEBUG) && defined(DEBUG_WAIT_FOR_SERIAL)
    // Várakozás a soros port megnyitására hibakereséshez
    Utils::debugWaitForSerial(tft);
#endif

    // Csak az általános információkat jelenítjük meg először (SI4735 nélkül)
    // Program cím és build info megjelenítése
    tft.setFreeFont();
    tft.setTextSize(2);
    tft.setTextColor(TFT_CYAN, TFT_BLACK);
    tft.setTextDatum(TC_DATUM);
    tft.drawString(PROGRAM_NAME, tft.width() / 2, 20);

    tft.setTextSize(1);
    tft.setTextColor(TFT_WHITE, TFT_BLACK);
    tft.setTextDatum(TC_DATUM);
    tft.drawString("Version " + String(PROGRAM_VERSION), tft.width() / 2, 50);
    tft.drawString(PROGRAM_AUTHOR, tft.width() / 2, 70);

    // Build info
    tft.setTextColor(TFT_YELLOW, TFT_BLACK);
    tft.setTextDatum(TC_DATUM);
    tft.drawString("Build: " + String(__DATE__) + " " + String(__TIME__), tft.width() / 2, 100);

    // Inicializálási progress
    tft.setTextColor(TFT_GREEN, TFT_BLACK);
    tft.setTextDatum(TC_DATUM);
    tft.drawString("Initializing...", tft.width() / 2, 140);

    // EEPROM inicializálása (A fordítónak muszáj megadni egy típust, itt most egy Config_t-t használunk, de igaziból mindegy)
    tft.drawString("Loading EEPROM...", tft.width() / 2, 160);
    StoreEepromBase<Config_t>::init(); // Meghívjuk a statikus init metódust

    // Ha a bekapcsolás alatt nyomva tartjuk a rotary gombját, akkor töröljük a konfigot
    if (digitalRead(PIN_ENCODER_SW) == LOW) {
        DEBUG("Encoder button pressed during startup, restoring defaults...\n");
        Utils::beepTick();
        delay(1500);
        if (digitalRead(PIN_ENCODER_SW) == LOW) { // Ha még mindig nyomják

            DEBUG("Restoring default settings...\n");
            Utils::beepTick();
            config.loadDefaults();
            fmStationStore.loadDefaults();
            amStationStore.loadDefaults();
            bandStore.loadDefaults();

            DEBUG("Alapértelmezett beállítások mentése...\n");
            Utils::beepTick();
            config.checkSave();
            bandStore.checkSave();
            fmStationStore.checkSave();
            amStationStore.checkSave();

            Utils::beepTick();
            DEBUG("Alapértelmezett beállítások visszaállítva!\n");
        }
    } else {
        // konfig betöltése
        tft.drawString("Configuration loading...", tft.width() / 2, 180);
        config.load();
    }

    // Rotary Encoder beállítása
    rotaryEncoder.setDoubleClickEnabled(true);                                   // Dupla kattintás engedélyezése
    rotaryEncoder.setAccelerationEnabled(config.data.rotaryAccelerationEnabled); // Gyorsítás engedélyezése a rotary enkóderhez
    // Pico HW Timer1 beállítása a rotaryhoz
    rotaryTimer.attachInterruptInterval(ROTARY_ENCODER_SERVICE_INTERVAL_IN_MSEC * 1000, rotaryTimerHardwareInterruptHandler);

    // Kell kalibrálni a TFT Touch-ot?
    if (Utils::isZeroArray(config.data.tftCalibrateData)) {
        Utils::beepError();
        Utils::tftTouchCalibrate(tft, config.data.tftCalibrateData);
        config.checkSave(); // Kalibrációs adatok mentése
    }

    // Beállítjuk a TFT touch screen-t
    tft.setTouch(config.data.tftCalibrateData);

    // Állomáslisták és band adatok betöltése az EEPROM-ból (a config után!)
    tft.drawString("Loading stations & bands...", tft.width() / 2, 200);
    bandStore.load(); // Band adatok betöltése
    fmStationStore.load();
    amStationStore.load();

    // ----------------------- Splash screen megjelenítése az inicializálás közben --------------------
#define SPLASH_SCREEN_PROGRESS_BAR_STEPS 7
    uint8_t splashProgressCnt = 1;
    // Most átváltunk a teljes splash screen-re az SI4735 infókkal
    SplashScreen *splash = new SplashScreen(tft);
    // Splash screen megjelenítése progress bar-ral
    splash->show(true, SPLASH_SCREEN_PROGRESS_BAR_STEPS); // SI4735 init és infók megjelenítése

    // --- Lépés 1: AudioController inicializálása
    splash->updateProgress(splashProgressCnt++, SPLASH_SCREEN_PROGRESS_BAR_STEPS, "AudioController initializing...");
    audioController.stopAudioController(); // Alaphelyzetbe állítás
    audioController.init();                // DC szint mérése az AD bemeneten (Core1)
    delay(100);

    // --- Lépés 2: I2C inicializálás
    splash->updateProgress(splashProgressCnt++, SPLASH_SCREEN_PROGRESS_BAR_STEPS, "Initializing SI4735 I2C...");
    // FIGYELEM!!! Az si473x (Nem a default I2C lábakon [4,5] van, hanem az PIN_SI4735_I2C_SDA és az PIN_SI4735_I2C_SCL lábakon !!!)
    Wire.setSDA(PIN_SI4735_I2C_SDA); // I2C for SI4735 SDA
    Wire.setSCL(PIN_SI4735_I2C_SCL); // I2C for SI4735 SCL
    Wire.begin();
    delay(300);

    // --- Lépés 3: SI4735Manager inicializálása itt
    splash->updateProgress(splashProgressCnt++, SPLASH_SCREEN_PROGRESS_BAR_STEPS, "Initializing SI4735Manager...");
    if (pSi4735Manager == nullptr) {
        pSi4735Manager = new Si4735Manager();
        // BandStore beállítása a Si4735Manager-ben
        pSi4735Manager->setBandStore(&bandStore);
    }
    // KRITIKUS: Band tábla dinamikus adatainak EGYSZERI inicializálása RÖGTÖN a Si4735Manager létrehozása után!
    pSi4735Manager->initializeBandTableData(true); // forceReinit = true az első inicializálásnál

    // --- Lépés 4: SI4735 lekérdezése
    splash->updateProgress(splashProgressCnt++, SPLASH_SCREEN_PROGRESS_BAR_STEPS, "Detecting SI4735...");
    int16_t si4735Addr = pSi4735Manager->getDeviceI2CAddress();
    if (si4735Addr == 0) {
        Utils::beepError();
        tft.fillScreen(TFT_BLACK);
        tft.setTextColor(TFT_RED, TFT_BLACK);
        tft.setTextSize(2);
        tft.setTextDatum(MC_DATUM);
        tft.drawString("SI4735 NOT DETECTED!", tft.width() / 2, tft.height() / 2);
        DEBUG("Si4735 not detected");
        while (true) // nem megyünk tovább
            ;
    }

    // --- Lépés 5: SI4735 konfigurálás
    splash->updateProgress(splashProgressCnt++, SPLASH_SCREEN_PROGRESS_BAR_STEPS, "Configuring SI4735...");
    pSi4735Manager->setDeviceI2CAddress(si4735Addr == 0x11 ? 0 : 1); // Sets the I2C Bus Address, erre is szükség van...
    splash->drawSI4735Info(pSi4735Manager->getSi4735());
    delay(300);

    // --- Lépés 6: Frekvencia beállítások
    splash->updateProgress(splashProgressCnt++, SPLASH_SCREEN_PROGRESS_BAR_STEPS, "Setting up radio...");
    pSi4735Manager->init(true);
    delay(100);

    // --- Lépés 7: Kezdő képernyő beállítása
    splash->updateProgress(splashProgressCnt++, SPLASH_SCREEN_PROGRESS_BAR_STEPS, "Preparing display...");
    const char *startScreenName = pSi4735Manager->getCurrentBandType() == FM_BAND_TYPE ? SCREEN_NAME_FM : SCREEN_NAME_AM;
    screenManager = new ScreenManager();
    screenManager->switchToScreen(startScreenName); // A kezdő képernyőre váltás
    delay(100);

    // Splash screen eltűntetése
    splash->hide();
    delete splash;

    //-----------------------------------------------------------------------------------------------
    PicoMemoryInfo::MemoryStatus_t memStatus = PicoMemoryInfo::getMemoryStatus();
    DEBUG("core-0: System clock: %u MHz, Heap: used: %u kB, free: %u kB\n", (unsigned)clock_get_hz(clk_sys) / 1000000u, memStatus.usedHeap / 1024u,
          memStatus.freeHeap / 1024);

    // Csippantunk egyet a végén
    Utils::beepTick();
}

/**
 * @brief Core0 fő ciklus függvénye
 */
void loop() {

    // EEPROM mentés figyelése
#define EEPROM_SAVE_CHECK_INTERVAL 1000 * 60 * 5 // 5 perc
    static uint32_t lastEepromSaveCheck = 0;
    if (Utils::timeHasPassed(lastEepromSaveCheck, EEPROM_SAVE_CHECK_INTERVAL)) {
        config.checkSave();         // Config mentése
        bandStore.checkSave();      // Band adatok mentése
        fmStationStore.checkSave(); // FM állomások mentése
        amStationStore.checkSave(); // AM állomások mentése
        lastEepromSaveCheck = millis();
    }

#ifdef SHOW_MEMORY_INFO
    // Memória információk megjelenítése ha engedélyezve van
    constexpr uint32_t MEMORY_INFO_INTERVAL = 20 * 1000; // 20mp
    static uint32_t lastDebugMemoryInfo = 0;
    if (Utils::timeHasPassed(lastDebugMemoryInfo, MEMORY_INFO_INTERVAL)) {
        PicoMemoryInfo::debugMemoryInfo();
        lastDebugMemoryInfo = millis();
    }
#endif

    // Touch események feldolgozása
    processTouchEvent();

    // Rotary Encoder események feldolgozása
    processRotaryEncoderEvent();

    // Képernyő loop-ok, képernyő iterációk, screensaver kezelése
    screenManager->loop();

    // SI4735 loop hívása, squelch és hardver némítás kezelése
    pSi4735Manager->loop();
}

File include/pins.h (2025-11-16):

/*
 * Project: [pico-radio-9] Raspberry Pi Pico Si4735 Radio                                                              *
 * File: pins.h                                                                                                        *
 * Created Date: 2025.11.07.                                                                                           *
 *                                                                                                                     *
 * Author: BT-Soft                                                                                                     *
 * GitHub: https://github.com/bt-soft                                                                                  *
 * Blog: https://electrodiy.blog.hu/                                                                                   *
 * -----                                                                                                               *
 * Copyright (c) 2025 BT-Soft                                                                                          *
 * License: MIT License                                                                                                *
 * 	Bárki szabadon használhatja, módosíthatja, terjeszthet, beépítheti más                                             *
 * 	projektbe (akár zártkódúba is), akár pénzt is kereshet vele                                                        *
 * 	Egyetlen feltétel:                                                                                                 *
 * 		a licencet és a szerző nevét meg kell tartani a forrásban!                                                     *
 * -----                                                                                                               *
 * Last Modified: 2025.11.16, Sunday  09:48:49                                                                         *
 * Modified By: BT-Soft                                                                                                *
 * -----                                                                                                               *
 * HISTORY:                                                                                                            *
 * Date      	By	Comments                                                                                           *
 * ----------	---	-------------------------------------------------------------------------------------------------  *
 */

#pragma once

// TFT (A TFT_eSPI_User_Setup.h-ban a pinout)

// I2C si4735
#define PIN_SI4735_I2C_SDA 8
#define PIN_SI4735_I2C_SCL 9
#define PIN_SI4735_RESET 10

// Audio FFT bemenet
#define PIN_AUDIO_INPUT A0 // A0/GPIO26 az FFT audio bemenethez

// Feszültségmérés
#define PIN_VBUS_EXTERNAL_MEASURE_INPUT A1 // A1/GPIO27 a VBUS mérésének feszültségosztós bemenetéhez

// Rotary Encoder
#define PIN_ENCODER_DT 17
#define PIN_ENCODER_CLK 16
#define PIN_ENCODER_SW 18

// Others
#define PIN_TFT_BACKGROUND_LED 1 // A NYÁK miatt áthelyezve a  GPIO1-es lábra
#define PIN_AUDIO_MUTE 19
#define PIN_BEEPER 20

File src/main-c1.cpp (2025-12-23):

/*
 * Project: [pico-radio-9] Raspberry Pi Pico Si4735 Radio                                                              *
 * File: main-c1.cpp                                                                                                   *
 * Created Date: 2025.11.07.                                                                                           *
 *                                                                                                                     *
 * Author: BT-Soft                                                                                                     *
 * GitHub: https://github.com/bt-soft                                                                                  *
 * Blog: https://electrodiy.blog.hu/                                                                                   *
 * -----                                                                                                               *
 * Copyright (c) 2025 BT-Soft                                                                                          *
 * License: MIT License                                                                                                *
 * 	Bárki szabadon használhatja, módosíthatja, terjeszthet, beépítheti más                                             *
 * 	projektbe (akár zártkódúba is), akár pénzt is kereshet vele                                                        *
 * 	Egyetlen feltétel:                                                                                                 *
 * 		a licencet és a szerző nevét meg kell tartani a forrásban!                                                     *
 * -----                                                                                                               *
 * Last Modified: 2025.12.20, Saturday  06:31:29                                                                       *
 * Modified By: BT-Soft                                                                                                *
 * -----                                                                                                               *
 * HISTORY:                                                                                                            *
 * Date      	By	Comments                                                                                           *
 * ----------	---	-------------------------------------------------------------------------------------------------  *
 */

#include <Arduino.h>
#include <algorithm>
#include <cstring>
#include <hardware/adc.h> // ADC hardware hozzáférés Core1 szenzor mérésekhez
#include <memory>

#include "AudioProcessor-c1.h"
#include "DecoderCW-c1.h"
#include "DecoderRTTY-c1.h"
#include "DecoderSSTV-c1.h"
#include "DecoderWeFax-c1.h"
#include "Utils.h"
#include "adc-constants.h"
#include "defines.h"

// Core-1 debug engedélyezése de csak DEBUG módban
#define __CORE1_DEBUG
#if defined(__DEBUG) && defined(__CORE1_DEBUG)
#define CORE1_DEBUG(fmt, ...) DEBUG(fmt __VA_OPT__(, ) __VA_ARGS__)
#else
#define CORE1_DEBUG(fmt, ...) // Üres makró, ha __DEBUG nincs definiálva
#endif

// A Core-1-nek stack külön legyen a Core-0-tól
// https://arduino-pico.readthedocs.io/en/latest/multicore.html#stack-sizes
bool core1_separate_stack = true;

//-------------------------------------------------------------------------------------
//  Globális osztott memóriaterületek a Core-0 és Core-1 között
//-------------------------------------------------------------------------------------
// Osztott adatpufferek Core-0 és Core-1 között
// A két elemű sharedData[2] tömb azért van, hogy a két mag (Core 0 és Core 1) között
// biztonságosan lehessen adatot cserélni, "ping-pong" vagy "double-buffering" technikával.
SharedData sharedData[2];
volatile uint8_t activeSharedDataIndex = 0; // Aktív SharedData index (0 vagy 1)

// A dekódolt adatok globális példánya, ezt éri el a Core-0 is
DecodedData decodedData;

// CORE1 szenzor adatok (Core1 olvassa az ADC-t, Core0 csak kijelzi!)
volatile float core1_VbusVoltage;    // VBUS feszültség (Volt) - Core1 méri ADC1-ről
volatile float core1_CpuTemperature; // CPU hőmérséklet (Celsius) - Core1 méri ADC4-ről

//-------------------------------------------------------------------------------------

// Audio feldolgozó példányja
static AudioProcessorC1 audioProcC1; // Static -> global instance

// Core-1 aktív dekóder azonosítója
static DecoderId activeDecoderIdCore1 = ID_DECODER_NONE;
std::unique_ptr<IDecoder> activeDecoderCore1 = nullptr;

//--- EEprom safe Writer segédfüggvények -------------------------------------------------------------------------------------

/**
 * @brief Core1 audio mintavételezés indítása
 */
void startAudioSamplingC1() { audioProcC1.start(); }

/**
 * @brief Core1 audio mintavételezés leállítása
 */
void stopAudioSamplingC1() { audioProcC1.stop(); }

/**
 * @brief Core1 audio mintavételezés fut?
 */
bool isAudioSamplingRunningC1() { return audioProcC1.isRunning(); }

/**
 * @brief Core1 szenzor mérések - VBUS feszültség és CPU hőmérséklet
 * @details Ez a függvény a Core1-en fut, így TELJES KONTROLLJA van az ADC felett.
 * BIZTONSÁGOS MÉRÉSI STRATÉGIA:
 * 1. Audio DMA SZÜNETEL a mérés alatt (ez FONTOS!)
 * 2. Arduino analogRead() / analogReadTemp() wrapper használata
 * 3. ADC csatorna visszaállítás ADC0-ra
 * 4. Audio DMA FOLYTATÁSA
 */
void readSensorsOnCore1() {

    // // BIZTONSÁGI ELLENŐRZÉS: Csak akkor mérünk, ha az audio DMA NEM fut
    // // Ha bármilyen audio feldolgozás aktív (FFT, CW, RTTY), NE szakítsuk meg a DMA-t
    // // → race condition elkerülése a Core0 TFT műveletekkel (spectrum rajzolás, stb.)
    // bool isAudioRunning = audioProcC1.isRunning();

    // if (isAudioRunning) {
    //     // Ha audio DMA fut, NE szakítsuk meg - a cache-olt értékek továbbra is elérhetők
    //     // (core1_VbusVoltage, core1_CpuTemperature)
    //     return;
    // }

    // Ha fut az Audio DMA, akkor lecsukjuk a mérés idejéig
    bool wasAudioActive = isAudioSamplingRunningC1();
    if (wasAudioActive) {
        stopAudioSamplingC1();
    }

    // CSAK akkor mérünk, ha az audio DMA teljesen inaktív (BIZTONSAGOS)

    // VBUS feszültség mérése 12-bit ADC olvasással
    float voltageOut = (analogRead(PIN_VBUS_EXTERNAL_MEASURE_INPUT) * CORE1_ADC_V_REFERENCE) / CORE1_ADC_CONVERSION_FACTOR;
    core1_VbusVoltage = voltageOut * CORE1_VBUSDIVIDER_RATIO;

    // CPU hőmérséklet mérése (analogReadTemp() is 12-bit az RP2040-en)
    core1_CpuTemperature = analogReadTemp();

    // KRITIKUS: ADC csatorna VISSZAÁLLÍTÁSA az audio bemenetre (ADC0)!
    adc_select_input(0); // ADC0 (GPIO26 = A0)

    // Audio DMA visszaindítása, ha előtte futott
    if (wasAudioActive) {
        startAudioSamplingC1();
    }

    CORE1_DEBUG("core-1: Sensors: VBUS=%.2fV, Temp=%.1f°C\n", //
                core1_VbusVoltage,                            //
                core1_CpuTemperature);
}
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

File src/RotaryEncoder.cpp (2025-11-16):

/*
 * Project: [pico-radio-9] Raspberry Pi Pico Si4735 Radio                                                              *
 * File: RotaryEncoder.cpp                                                                                             *
 * Created Date: 2025.11.07.                                                                                           *
 *                                                                                                                     *
 * Author: BT-Soft                                                                                                     *
 * GitHub: https://github.com/bt-soft                                                                                  *
 * Blog: https://electrodiy.blog.hu/                                                                                   *
 * -----                                                                                                               *
 * Copyright (c) 2025 BT-Soft                                                                                          *
 * License: MIT License                                                                                                *
 * 	Bárki szabadon használhatja, módosíthatja, terjeszthet, beépítheti más                                             *
 * 	projektbe (akár zártkódúba is), akár pénzt is kereshet vele                                                        *
 * 	Egyetlen feltétel:                                                                                                 *
 * 		a licencet és a szerző nevét meg kell tartani a forrásban!                                                     *
 * -----                                                                                                               *
 * Last Modified: 2025.11.16, Sunday  09:41:44                                                                         *
 * Modified By: BT-Soft                                                                                                *
 * -----                                                                                                               *
 * HISTORY:                                                                                                            *
 * Date      	By	Comments                                                                                           *
 * ----------	---	-------------------------------------------------------------------------------------------------  *
 */

// inspired:  http://www.mikrocontroller.net/articles/Drehgeber

#include "RotaryEncoder.h"

// ----------------------------------------------------------------------------
// Gomb konfiguráció (értékek 1ms-os időzítő szolgáltatás hívásokhoz)
//
#define ENC_BUTTONINTERVAL 10   // gomb ellenőrzése x milliszekundumonként, egyben a pattogásgátló idő is
#define ENC_DOUBLECLICKTIME 600 // második kattintás 600ms-on belül
#define ENC_HOLDTIME 1200       // a gomb lenyomva tartásának jelentése 1.2s után

// ----------------------------------------------------------------------------
// Gyorsulás konfiguráció (1000Hz-es ::service() hívásokhoz)
// #define ENC_ACCEL_TOP 3072  // max. gyorsulás: *12 (val >> 8)
#define ENC_ACCEL_TOP 6400 // max. gyorsulás: *25 (val >> 8)
#define ENC_ACCEL_INC 50   // gyorsulás növelése
#define ENC_ACCEL_DEC 2    // lassítás mértéke

// ----------------------------------------------------------------------------

#if ENC_DECODER != ENC_NORMAL
#ifdef ENC_HALFSTEP
// dekódolási táblázat hibás léptető hardverhez (fél felbontás)
const int8_t ClickEncoder::table[16] __attribute__((__progmem__)) = {0, 0, -1, 0, 0, 0, 0, 1, 1, 0, 0, 0, 0, -1, 0, 0};
#else
// dekódolási táblázat normál hardverhez
const int8_t ClickEncoder::table[16] __attribute__((__progmem__)) = {0, 1, -1, 0, -1, 0, 0, 1, 1, 0, 0, -1, 0, -1, 1, 0};
#endif
#endif

/**
 * Konstruktor
 */
RotaryEncoder::RotaryEncoder(uint8_t A, uint8_t B, uint8_t BTN, uint8_t stepsPerNotch, bool pinsActive)
    : pinA(A), pinB(B), pinBTN(BTN), steps(stepsPerNotch), pinsActive(pinsActive), doubleClickEnabled(true), accelerationEnabled(true), delta(0), last(0), acceleration(0), buttonState(ButtonState::Open) {

    uint8_t mode = (pinsActive == LOW) ? INPUT_PULLUP : INPUT;
    pinMode(pinA, mode);
    pinMode(pinB, mode);
    pinMode(pinBTN, mode);

    if (digitalRead(pinA) == pinsActive) {
        last = 3;
    }

    if (digitalRead(pinB) == pinsActive) {
        last ^= 1;
    }
}

/**
 * Megszakításból hívogatjuk 1msec-enként
 */
void RotaryEncoder::service() {
    bool moved = false;
    unsigned long now = millis();

    if (accelerationEnabled) { // lassítás minden ciklusban
        acceleration -= ENC_ACCEL_DEC;
        if (acceleration & 0x8000) { // MSB be van állítva, túlcsordulás kezelése
            acceleration = 0;
        }
    }

#if ENC_DECODER == ENC_FLAKY
    last = (last << 2) & 0x0F;

    if (digitalRead(pinA) == pinsActive) {
        last |= 2;
    }

    if (digitalRead(pinB) == pinsActive) {
        last |= 1;
    }

    uint8_t tbl = pgm_read_byte(&table[last]);
    if (tbl) {
        delta += tbl;
        moved = true;
    }
#elif ENC_DECODER == ENC_NORMAL
    int8_t curr = 0;

    if (digitalRead(pinA) == pinsActive) {
        curr = 3;
    }

    if (digitalRead(pinB) == pinsActive) {
        curr ^= 1;
    }

    int8_t diff = last - curr;

    if (diff & 1) { // 0. bit = lépés
        last = curr;
        delta += (diff & 2) - 1; // 1. bit = irány (+/-)
        moved = true;
    }
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

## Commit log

2025-11-07 Core1 Audio logic
    [pico-radio-5 - bill of materials.csv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]
2025-11-07 Add file headers and implement station storage functionality
    - Added file headers to multiple source files including AdcDma-c1.cpp, AudioController.cpp, AudioProcessor-c1.cpp, BandStore.cpp, Config.cpp, CwDecoder-c1.cpp, DebugDataInspector.cpp, RotaryEncoder.c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
    - Introduced PicoMemoryInfo.h and PicoMemoryInfo.cpp for memory status querying and debugging.
    - Created PicoSensorUtils.h and PicoSensorUtils.cpp for sensor-related functionalities including VBUS and temperature readings.
    - Implemented StationStore.h and StationStor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
2025-11-07 Implement Si4735 radio management and RDS functionality
    - Added Si4735Manager class to handle Si4735 radio operations including initialization, volume control, and squelch management.
    - Implemented Si4735Rds class for managing RDS features such as retrieving station names, program types, and radio text.
    - Introduced caching mechanisms for signal quality data in Si4735Runtime to optimize performance.
    - Defined runtime variables in rtVars for managing frequency display, BFO states, and mute functionality.
    - Enhanced audio mute management for better noise suppression during frequency changes.
    [main.cpp]
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2025-11-08 Add UIValueChangeDialog class for dynamic value adjustments
    - Implemented constructors for integer, float, boolean, and uint8_t types.
    - Added methods for incrementing and decrementing values with validation.
    - Created UI components for value modification, including +/- buttons for numeric types and TRUE/FALSE buttons for boolean.
    - Implemented value clamping and notification callbacks for value changes.
    - Enhanced drawing methods to display current values and update UI accordingly.
    - Added rotary event handling for intuitive user interaction.
2025-11-08 Fix initial screen switch to use the correct band type
    [main.cpp]
2025-11-08 Add UI components for stereo indicator and frequency input dialog
    - Implemented UICompStereoIndicator for displaying stereo/mono status with visual feedback.
    - Developed UIFrequencyInputDialog for user input of frequency with validation and dynamic layout.
    - Introduced UIHorizontalButtonBar for creating a responsive button layout with multiple rows.
    - Created UIMultiButtonDialog for displaying multiple button options with customizable behavior and layout.
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2025-11-09 Refactor code structure for improved readability and maintainability
    [pico-radio-5.kicad_sch]
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2025-11-12 Refactor and cleanup codebase
    - Updated debug message handling in defines.h to clarify serial wait functionality.
    - Removed obsolete bill of materials CSV file from KiCad project.
    - Deleted outdated backup ZIP files from KiCad project.
    - Added USB serial port settings in platformio.ini for improved monitoring.
    - Enhanced AudioProcessorC1 class to manage DMA sampling state more effectively.
    - Cleaned up debug messages in ScreenAM and ScreenAMCW classes for better readability.
    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
    [pico-radio-5 - bill of materials.csv]
2025-11-13 Add RTTY functionality and refactor related components
    - Introduced ScreenAMRTTY for RTTY decoding display and handling.
    - Updated configuration structure to include rttyShiftFrequency and rttyBaudRate.
    - Refactored existing code to replace rttyShiftHz with rttyShiftFrequency.
    - Enhanced UI components to support RTTY settings and display.
    - Updated debug output to reflect new RTTY parameters.
    [decoder_api.h]
2025-11-13 Add AGC and noise reduction control methods; implement command handling for settings
    [decoder_api.h, main-c1.cpp]
2025-11-14 HWSW mutestat + kicad file rename
    [pico-radio-9.kicad_pcb, pico-radio-9.kicad_sch]
2025-11-14 Refactor audio processing parameters and enhance debugging output; update noise reduction settings and spectrum data handling
    [decoder_api.h]
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2025-11-15 Update CW and RTTY display modes to improve initial visualization; enable noise reduction and adjust smoothing points for better audio clarity
    [decoder_api.h]
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2025-11-22 Update DecoderCW_C1 and ScreenAMCW: Implement adaptive threshold control in DecoderCW_C1, reset AGC initialization when disabled, and modify last modified timestamps in multiple files.
    [DecoderCW-c1.h, decoder_api.h]
2025-11-22 Update DecoderCW_C1: Adjust AGC parameters for stability, implement debounce logic for tone detection, and modify last modified timestamps.
    [DecoderCW-c1.h]
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2025-11-22 Add reset functionality for decoders and update last modified timestamps
    [decoder_api.h, main-c1.cpp]
2025-11-22 Update decoders and screens: add reset functionality, modify last modified timestamps, and fix method names
    [DecoderWeFax-c1.h, decoder_api.h]
2025-11-22 Update DecoderWeFax and ScreenAMWeFax: modify last modified timestamps, enhance reset functionality, and adjust button positioning
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2025-11-29 Update last modified timestamps and correct audio frequency constant naming
    [defines.h]
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2025-12-02 Increase filter sizes for improved noise reduction in WeFax and RTTY decoders; update comments for clarity and debugging enhancements
    [DecoderWeFax-c1.h]
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2025-12-02 Enhance RTTY decoder documentation and parameters; update noise handling constants for improved performance
    [decoder_api.h]
2025-12-03 Add fldigi WPM tracking and noise spike filtering to DecoderCW_C1; initialize limits and thresholds for improved decoding accuracy
    [DecoderCW-c1.h]
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2025-12-23 Add UICompTuningBar component for spectrum visualization
    - Implemented UICompTuningBar class to display a tuning bar for frequency spectrum analysis.
    - Added methods for updating spectrum data, drawing the tuning bar, and managing frequency markers.
    - Integrated peak hold logic for better visualization of signal strength over time.
    - Included color coding for bar heights based on magnitude.
    - Optimized rendering with sprite support for improved performance.
    [pico-radio-9.kicad_pcb, pico-radio-9.kicad_sch]
2025-12-24 Kicad PCB design
    [pico-radio-9.kicad_pcb, pico-radio-9.kicad_sch]
2025-12-24 -Print DC offset voltage in the log during init - Double-sided PCB design start
    [pico-radio-9-kétoldalas.kicad_pcb, pico-radio-9-kétoldalas.kicad_sch]
2025-12-25 Dual side PCB
    [pico-radio-9-kétoldalas.kicad_pcb, pico-radio-9-kétoldalas.kicad_sch]
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2025-12-25 PCB fabric order files
    [pico-radio-5-B_Cu.gbr, pico-radio-5-B_Mask.gbr, pico-radio-5-B_Silkscreen.gbr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]
2025-12-26 Dual sided PCB update
    [pico-radio-9-kétoldalas-B_Cu.gbr, pico-radio-9-kétoldalas-B_Mask.gbr, pico-radio-9-kétoldalas-B_Silkscreen.gbr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]
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2025-12-26 Update WEFAX_RAW_SAMPLES_SIZE to improve FM demodulator filter stability and clarify FFT resolution compromise
    [decoder_api.h]
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2026-01-05 Dual sided PCB
    [pico-radio-9-kétoldalas-B_Cu.gbr, pico-radio-9-kétoldalas-B_Silkscreen.gbr, pico-radio-9-kétoldalas-Edge_Cuts.gbr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]
2026-01-05 Vsys - Vbus power modification
    [pico-radio-9-B_Cu.gbr, pico-radio-9-B_Mask.gbr, pico-radio-9-B_Silkscreen.gbr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]
2026-01-28 Add capacitors C13 and C14 to the schematic and update connections
    - Added capacitor C13 (100nF) at coordinates (96.52, 148.59) with appropriate properties.
    - Added capacitor C14 (100nF) at coordinates (96.52, 171.45) with appropriate properties.
    - Updated wire connections for C13 and C14.
    - Changed the value of resistor R1 from 100k to 47k.
    - Adjusted the position of capacitor C7 for better layout.
    [pico-radio-9-B_Cu.gbr, pico-radio-9-B_Mask.gbr, pico-radio-9-B_Silkscreen.gbr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]
